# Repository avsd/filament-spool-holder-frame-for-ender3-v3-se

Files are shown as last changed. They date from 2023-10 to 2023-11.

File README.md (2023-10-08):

# Filament spool holder frame for Ender3 V3 SE

[][cc-by]

Balanced filament spool holder frame for Ender3 V3 SE.

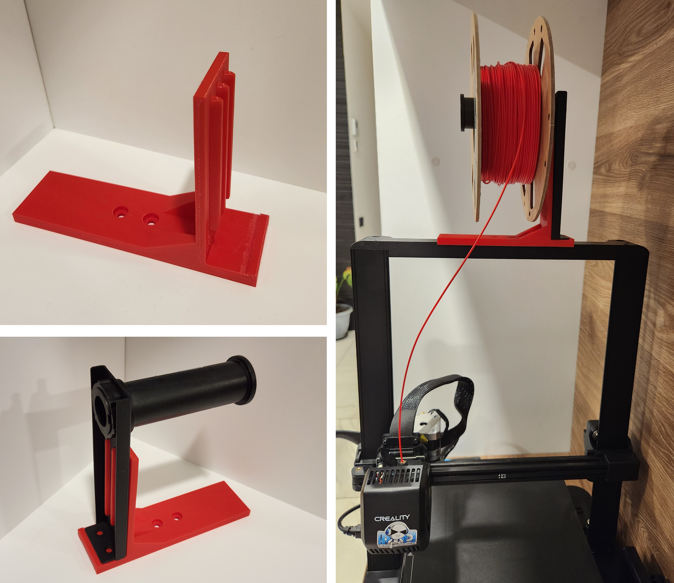
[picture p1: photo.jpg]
Photos


The spool is rotated 90º, and moved so that the spool hangs
above the gantry in the middle of it, making
centre of the mass right at the center. It zeroes out
all possible torques caused by filament weight,
resulting into more consistent printing.

* Easy to print
* No additional screws needed
* Reinforced by using 3D-printer's original steel spool holder
* No support required
* 20% or more infill is recommended

Inspired by [Clslee Lee's](https://www.printables.com/@ClsleeLee_1097777) 
[model](https://www.printables.com/model/572862-ender-3-v3-se-spool-holder)
(although not a remix of it).

## License

This work is licensed under a
[Creative Commons Attribution 4.0 International License][cc-by].

[][cc-by]

[cc-by]: http://creativecommons.org/licenses/by/4.0/
[cc-by-image]: https://i.creativecommons.org/l/by/4.0/88x31.png
[cc-by-shield]: https://img.shields.io/badge/License-CC%20BY%204.0-lightgrey.svg

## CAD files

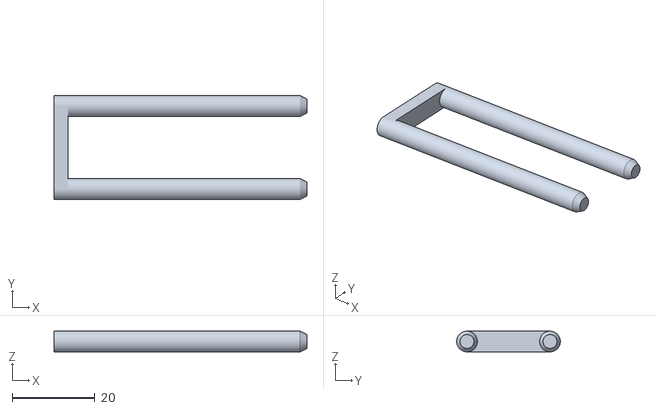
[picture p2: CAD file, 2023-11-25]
elevated-pins.stl
61.0 x 25.0 x 5.00

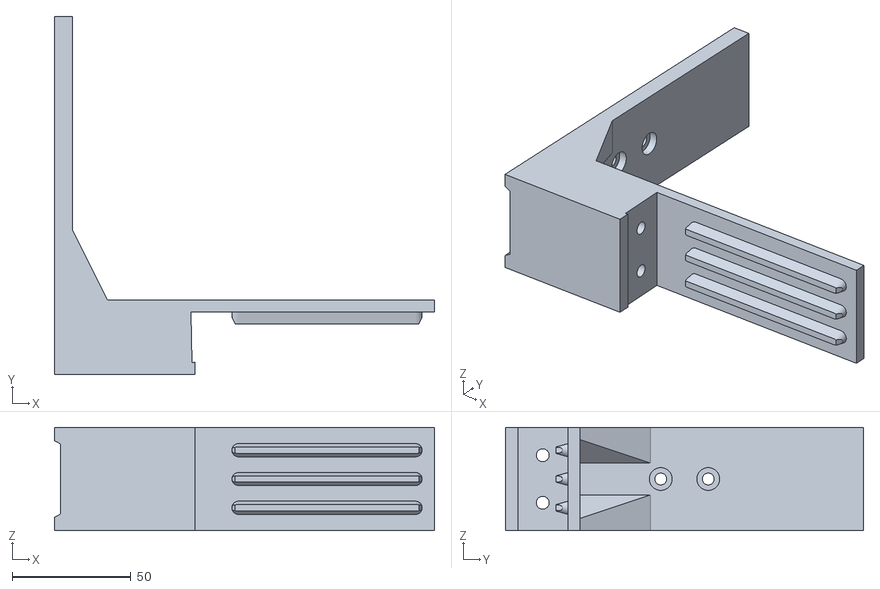
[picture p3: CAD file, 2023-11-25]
elevated-spool-holder-with-pins.stl
160.0 x 150.8 x 43.5

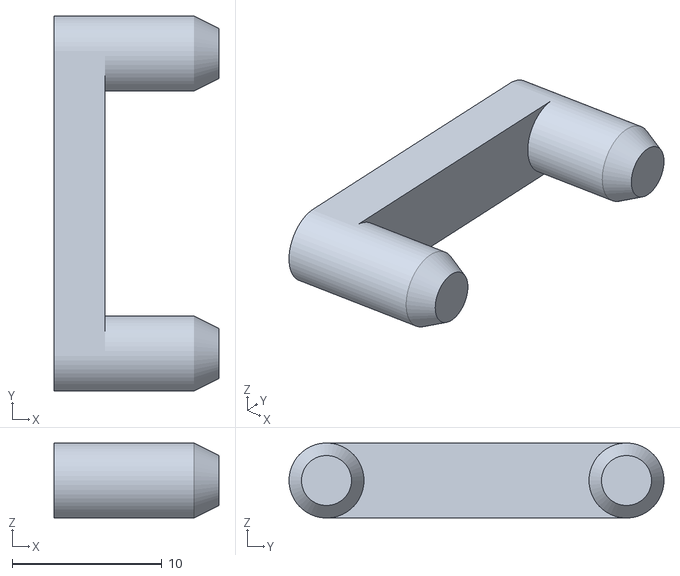
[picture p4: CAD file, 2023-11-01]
pins.stl
11.0 x 25.0 x 5.00

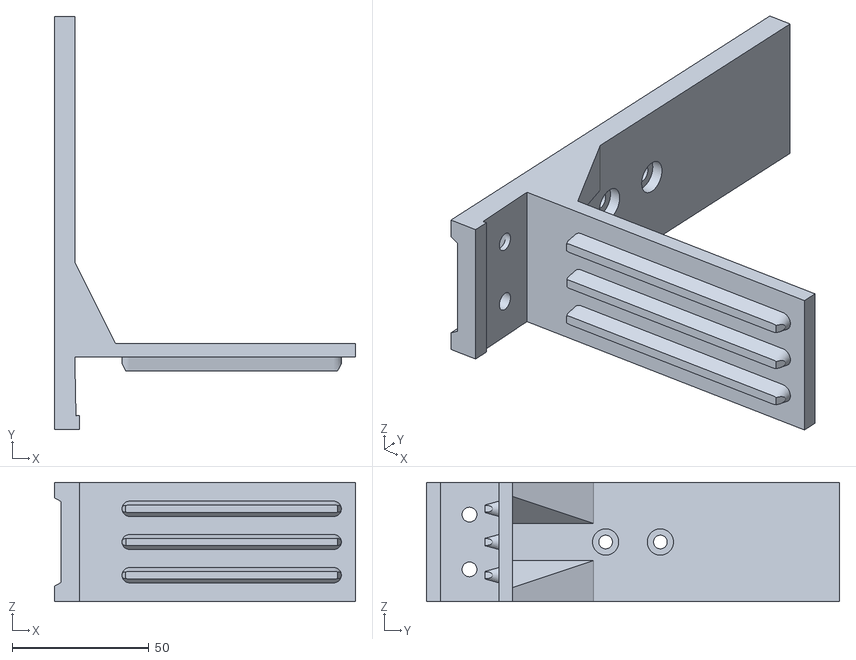
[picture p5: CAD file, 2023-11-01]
spool-holder-with-pins.stl
110.0 x 150.8 x 43.5

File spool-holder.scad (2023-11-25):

/**
 * Balanced filament spool holder, rotated 90º, making
 * rotation axis parallel to the gantry, and centre of
 * the mass right in the middle of it. It zeroes out
 * all possible torques caused by filament weight,
 * resultin to more consistent printing.
 *
 * Inspired by this model (although not a remix):
 * https://www.printables.com/model/572862-ender-3-v3-se-spool-holder
 *
 * © David Avsajanishvili <david@davidavs.com> 2023
 */

// Width of the top gantry (mm)
gantryWidth = 29.5;

// Width of the original spool holder (mm)
holderWidth = 43.5;

// Width of the back bottom part of the original holder (the one with holes) (mm)
holderBackBottomWidth = 21;

// Thickness of the material from which the original spool holder is made (mm)
holderMaterialThickness = 1.6;

// Diameter of the fixation holes on the original spool holder (mm)
holderScrewHolesDiameter = 5;

// Distance between the fixation holes on the original spool holder (mm)
holderScrewHolesDistance = 20;

// Diameter of the screw head (mm)
holderScrewHeadDiameter = 9.2;

// Width of each of the 3 vertical holes on the original spool holder (mm)
holderVerticalMiddleHoleWidth = 5.85;
holderVerticalSideHolesWidth = 6.00;

// Length of each of the 3 vertical holes on the original spool holder (mm)
holderVerticalHolesLength = 80.50;

// Height of each of the 3 vertical holes from the surface of the gantry (mm)
holderVerticalHolesHeight = 17;

// Distance between the 3 vertical holes (mm)
holderVerticalHolesDistance = 6.2;
holderVerticalHolesMiddleDistance = holderVerticalHolesDistance + (
    holderVerticalMiddleHoleWidth + holderVerticalSideHolesWidth
) / 2;

// Length of the active part of the holder roller (mm)
holderRollerLength = 98;

// Additional elevation of the holder (to hold non-standard spools with larger diameter)
elevation = 0;

// Thickness of all parts of the new holder frame (mm)
frameThickness = 5;

// Length of the vertical cathetus of enforcing triangles (mm)
enforcingTriangleVerticalLength = 15;

// Length of the horizontal cathetus of enforcing triangle (mm)
enforcingTriangleHorizontalLength = 30;

// Width of the enforcing triangle base (mm)
enforcingTriangleBaseWidth = 15;

// Depth of the extension that goes to the middle vertical hole (mm)
extensionDepth = 5;

// Height of the back stop (mm)
bottomStopHeight = 1.6;

// Thickness of the part where screw goes (mm)
screwHoleThickness = 1.6;

// Length of the pins to go into the original holder holes
pinLength = 6;

// Allowance for fitting (mm, from ech side!)
allowance = 0.2;


bottomLength = holderRollerLength + (frameThickness + holderBackBottomWidth + 2 * allowance) * 2;
onlyPins = false;
withPins = true;

module bottomHole()
    translate([0, bottomLength / 2, holderWidth / 2])
        rotate([0, 90, 0])
            union() {
                linear_extrude(frameThickness * 5)
                    circle(holderScrewHolesDiameter / 2, $fn=50);
                translate([0, 0, frameThickness + screwHoleThickness]) linear_extrude(frameThickness * 5)
                    circle(holderScrewHeadDiameter / 2 + allowance, $fn=50);
            };
module bottomPart() difference() {
    union() {
        translate([-frameThickness, 0, 0]) linear_extrude(holderWidth)
            square([frameThickness, bottomLength]);
        if (elevation > 0) linear_extrude(holderWidth) square([elevation, frameThickness * 2 + holderBackBottomWidth]);
    };
    union() {
        translate([-frameThickness * 2, -holderScrewHolesDistance / 2, 0]) bottomHole();
        translate([-frameThickness * 2, +holderScrewHolesDistance / 2, 0]) bottomHole();
    }
};

module backPart() translate([elevation, 0, 0]) linear_extrude(holderWidth)
    polygon([
        [0, 0],
        [0, frameThickness + holderBackBottomWidth - holderMaterialThickness],
        [allowance * 2, frameThickness],
        [bottomStopHeight, frameThickness + allowance],
        [bottomStopHeight, 0]
    ]);


module extension(width, offset) {
    translate([
        elevation + holderVerticalHolesHeight + holderVerticalHolesLength / 2,
        frameThickness + holderBackBottomWidth + allowance * 2,
        holderWidth / 2 + offset
    ])
        rotate([90, 0, 0])
            intersection() {
                linear_extrude(extensionDepth, scale=[1, 0.5])
                    hull() {
                        translate([-(holderVerticalHolesLength - width) / 2, 0, 0])
                            circle(width / 2 - allowance, $fn=50);
                        translate([+(holderVerticalHolesLength - width) / 2, 0, 0])
                            circle(width / 2 - allowance, $fn=50);
                    }
                linear_extrude(
                    extensionDepth,
                    scale=[1 - extensionDepth / holderVerticalHolesLength, 1]
                )
                    hull() {
                        translate([-(holderVerticalHolesLength) / 2, 0, 0])
                            square([width / 3, width], center=true);
                        translate([+(holderVerticalHolesLength) / 2, 0, 0])
                            square([width / 3, width], center=true);
                    }
            }
        
};

module sidePart() union() {
    // frame
    translate([0, frameThickness + holderBackBottomWidth + 2 * allowance, 0])
        linear_extrude(holderWidth)
            square([
                elevation + holderVerticalHolesLength + holderVerticalHolesHeight + frameThickness,
                frameThickness
            ]);

    // extensions
    extension(holderVerticalMiddleHoleWidth, 0);
    extension(holderVerticalSideHolesWidth, holderVerticalHolesMiddleDistance);
    extension(holderVerticalSideHolesWidth, -holderVerticalHolesMiddleDistance);
}

module bottomSide(mirrorIndex)
    translate([-frameThickness, 0, holderWidth / 2])
        mirror([0, 0, mirrorIndex])
            translate([0, 0, -holderWidth / 2])
                rotate([0, -90, 0])
                    linear_extrude(frameThickness / 2, scale=[0.8, 1])
                        square([(holderWidth - gantryWidth) / 2, bottomLength]);

module enforcingTriangle(mirrorIndex)
    translate([0, frameThickness * 2 + holderBackBottomWidth, holderWidth / 2])
        mirror([0, 0, mirrorIndex])
            translate([0, 0, holderWidth / 2])
                rotate([0, 90, 0])
                    linear_extrude(enforcingTriangleVerticalLength, scale=[frameThickness / enforcingTriangleBaseWidth, 0])
                        square([enforcingTriangleBaseWidth, enforcingTriangleHorizontalLength]);

module pins(slots=false) translate([
    0,
    frameThickness + holderBackBottomWidth / 2 + allowance,
    holderWidth / 2,
]) rotate([0, 90, 0])
    for(m = [0, 1]) mirror([m, 0, 0]) translate([holderScrewHolesDistance / 2, 0, -frameThickness - allowance]) {
        if (slots) {
            linear_extrude(elevation + frameThickness * 5) circle(holderScrewHolesDiameter / 2 + allowance, $fn=50);
            linear_extrude(frameThickness - screwHoleThickness + allowance) hull() {
                circle(holderScrewHolesDiameter / 2 + allowance, $fn=50);
                translate([-holderScrewHolesDistance / 2, 0, 0])
                    square(holderScrewHolesDiameter + allowance * 2, center=true);
            }
        } else {
            hull() {
                linear_extrude(elevation + frameThickness + pinLength) circle(holderScrewHolesDiameter / 3, $fn=50);
                linear_extrude(elevation + frameThickness + pinLength - holderScrewHolesDiameter / 3)
                    circle(holderScrewHolesDiameter / 2, $fn=50);
            }
            linear_extrude(frameThickness - screwHoleThickness) hull() {
                circle(holderScrewHolesDiameter / 2, $fn=50);
                translate([-holderScrewHolesDistance / 2, 0, 0])
                    square(holderScrewHolesDiameter, center=true);
            }
        }
    }
    

module holderWithoutPins() {
    bottomPart();
    sidePart();
    enforcingTriangle(0);
    enforcingTriangle(1);
    backPart();
    bottomSide(0);
    bottomSide(1);
};

module holderWithPins() difference() { holderWithoutPins(); pins(slots=true); };

if (onlyPins) {
    rotate([90, 0, 0]) pins();
} else if (withPins) {
    holderWithPins();
} else {
    holderWithoutPins();
}

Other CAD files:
spool-holder.stl

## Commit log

2023-10-08 Initial revision
    [spool-holder.scad, spool-holder.stl]
2023-10-08 Rework enforcing triangles and bottom sides
    [spool-holder.scad, spool-holder.stl]
2023-10-08 Model fixes after first failed print
    [spool-holder.scad, spool-holder.stl]
2023-10-09 Separate variable for back stop height
    [spool-holder.scad]
2023-10-09 Rename variables
    [spool-holder.scad]
2023-11-01 Add a variant with pins
    [spool-holder.scad]
2023-11-01 Add build and stls
    [pins.stl, spool-holder-with-pins.stl]
2023-11-25 Add elevated version for 2kg spool holder
    [elevated-pins.stl, elevated-spool-holder-with-pins.stl, spool-holder.scad]

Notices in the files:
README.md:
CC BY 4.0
